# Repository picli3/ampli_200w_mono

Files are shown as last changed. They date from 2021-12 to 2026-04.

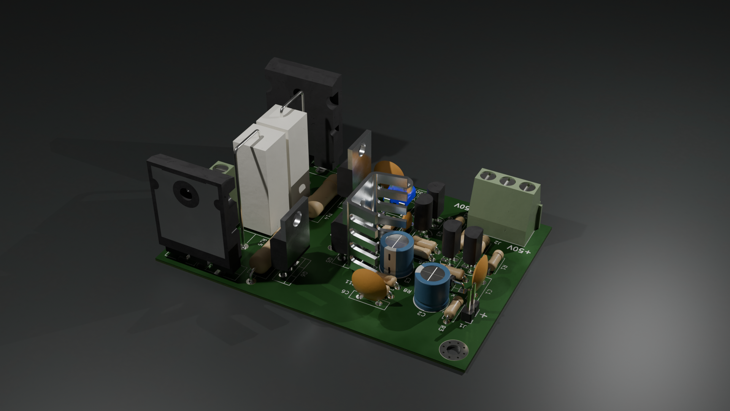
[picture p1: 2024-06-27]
untitled.png

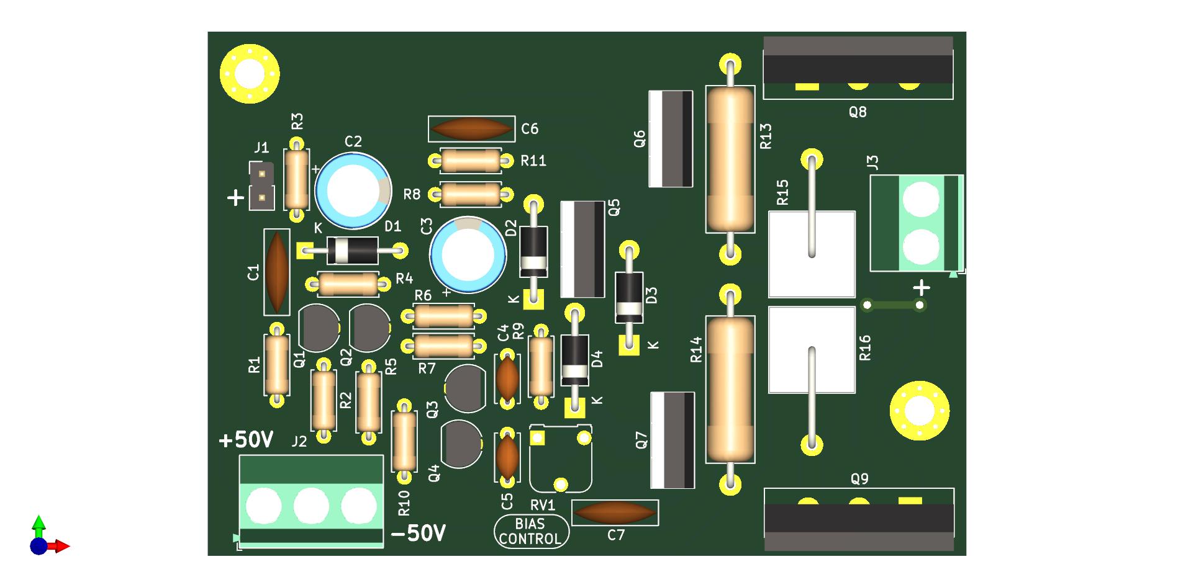
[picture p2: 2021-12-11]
pdf/amplificador_200w.jpg

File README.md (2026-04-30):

# ampli_200w_mono

Amplificador mono de alta potencia, orientado a aplicaciones de audio DIY donde se requiere una sola vía robusta de salida.

## Qué incluye
- esquemáticos o archivos de diseño en KiCad
- PCB o documentación asociada
- base reutilizable para análisis, fabricación o mejora del proyecto

## Propósito general
Este repositorio busca concentrar el diseño de hardware del proyecto en un formato editable y reutilizable, facilitando pruebas, documentación y futuras iteraciones del circuito.

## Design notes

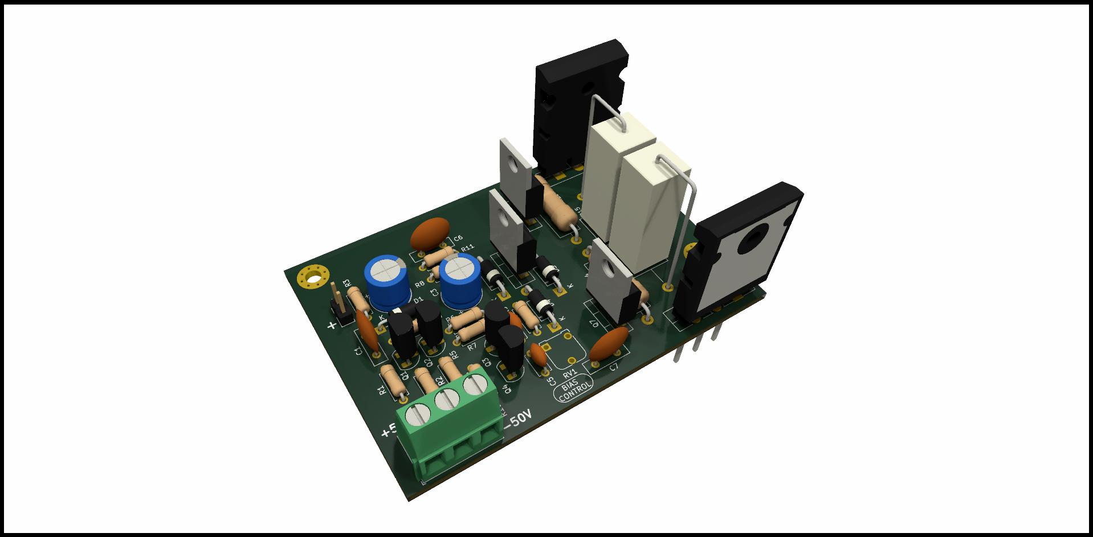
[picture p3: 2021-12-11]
pdf/amplificador_200w_ISO.jpg

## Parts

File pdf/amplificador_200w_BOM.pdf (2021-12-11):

amplificador_200w

Página 1

## AMPLIFICADOR 100W

Qty | Reference(s) | Value | Footprint | V | W
1 C1 | | 0.47uF | Capacitor_THT:C_Disc_D9.0mm_W2.5mm_P5.00mm
2 C2, C3 | | 100uF | Capacitor_THT:CP_Radial_D8.0mm_P3.50mm | 50V
2 C4, C5 | | 10pF | Capacitor_THT:C_Disc_D5.0mm_W2.5mm_P5.00mm
2 C6, C7 | | 10nF | Capacitor_THT:C_Disc_D9.0mm_W2.5mm_P5.00mm
1 D1 | | 24V | Diode_THT:D_A-405_P10.16mm_Horizontal
3 D2, D3, D4 | | 1N4007 | Diode_THT:D_DO-41_SOD81_P10.16mm_Horizontal
1 J1 | | Conn_01x03 | Connector_PinHeader_2.54mm:PinHeader_1x02_P2.54mm_Vertical
1 J2 | | Conn_01x03 | TerminalBlock_Phoenix:TerminalBlock_Phoenix_MKDS-1,5-3-5.08_1x03_P5.08mm_Horizontal
1 J3 | | Conn_01x02 | TerminalBlock_Phoenix:TerminalBlock_Phoenix_MKDS-1,5-2-5.08_1x02_P5.08mm_Horizontal
2 Q1, Q2 | | A733 | Package_TO_SOT_THT:TO-92L_HandSolder
2 Q3, Q4 | | 2SC2229 | Package_TO_SOT_THT:TO-92L_HandSolder
2 Q5, Q7 | | TIP42 | Package_TO_SOT_THT:TO-220-3_Vertical
1 Q6 | | TIP41 | Package_TO_SOT_THT:TO-220-3_Vertical
2 Q8, Q9 | | 2SC5200 | Package_TO_SOT_THT:TO-264-3_Vertical
2 R1, R7 | | 68K | Resistor_THT:R_Axial_DIN0207_L6.3mm_D2.5mm_P7.62mm_Horizontal | | 1/4W
2 R2, R5 | | 3.3K | Resistor_THT:R_Axial_DIN0207_L6.3mm_D2.5mm_P7.62mm_Horizontal | | 1/4W
1 R3 | | 4.7K | Resistor_THT:R_Axial_DIN0207_L6.3mm_D2.5mm_P7.62mm_Horizontal | | 1/4W
1 R4 | | 33K | Resistor_THT:R_Axial_DIN0207_L6.3mm_D2.5mm_P7.62mm_Horizontal | | 1/4W
1 R6 | | 1K | Resistor_THT:R_Axial_DIN0207_L6.3mm_D2.5mm_P7.62mm_Horizontal | | 1/4W
3 R8, R10, R11 | | 150 | Resistor_THT:R_Axial_DIN0207_L6.3mm_D2.5mm_P7.62mm_Horizontal | | 1/4W
1 R9 | | 10K | Resistor_THT:R_Axial_DIN0207_L6.3mm_D2.5mm_P7.62mm_Horizontal | | 1/4W
2 R13, R14 | | 100 | Resistor_THT:R_Axial_DIN0516_L15.5mm_D5.0mm_P20.32mm_Horizontal | | 2W
2 R15, R16 | | 0.33 | Resistor_THT:R_Axial_Power_L25.0mm_W9.0mm_P10.16mm_Vertical | | 5W
1 RV1 | | 200 | Potentiometer_THT:Potentiometer_Runtron_RM-065_Vertical

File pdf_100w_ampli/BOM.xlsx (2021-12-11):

Item | Qty | Reference(s) | Value | LibPart | Footprint | Datasheet | V
1 | 1 | C1 | 0.47uF | Device:C | Capacitor_THT:C_Disc_D9.0mm_W2.5mm_P5.00mm | ~
2 | 2 | C2, C3 | 100uF | Device:CP1 | Capacitor_THT:CP_Radial_D8.0mm_P3.50mm | ~ | 50V
3 | 2 | C4, C5 | 10pF | Device:C | Capacitor_THT:C_Disc_D5.0mm_W2.5mm_P5.00mm | ~
4 | 2 | C6, C7 | 10nF | Device:C | Capacitor_THT:C_Disc_D9.0mm_W2.5mm_P5.00mm | ~
5 | 1 | D1 | 24V | Device:D_Zener_ALT | Diode_THT:D_A-405_P10.16mm_Horizontal | ~
6 | 3 | D2, D3, D4 | 1N4007 | Device:D_ALT | Diode_THT:D_DO-41_SOD81_P10.16mm_Horizontal | ~
7 | 2 | H1, H2 | MountingHole | Mechanical:MountingHole | MountingHole:MountingHole_3.2mm_M3_Pad_Via | ~
8 | 1 | J1 | Conn_01x03 | Connector_Generic:Conn_01x02 | Connector_PinHeader_2.54mm:PinHeader_1x02_P2.54mm_Vertical | ~
9 | 1 | J2 | Conn_01x03 | Connector_Generic:Conn_01x03 | TerminalBlock_Phoenix:TerminalBlock_Phoenix_MKDS-1,5-3-5.08_1x03_P5.08mm_Horizontal | ~
10 | 1 | J3 | Conn_01x02 | Connector_Generic:Conn_01x02 | TerminalBlock_Phoenix:TerminalBlock_Phoenix_MKDS-1,5-2-5.08_1x02_P5.08mm_Horizontal | ~
11 | 2 | Q1, Q2 | A733 | Device:Q_PNP_EBC | Package_TO_SOT_THT:TO-92L_HandSolder | https://www.voti.nl/docs/A733.pdf
12 | 2 | Q3, Q4 | 2SC2229 | Device:Q_NPN_ECB | Package_TO_SOT_THT:TO-92L_HandSolder | ~
13 | 2 | Q5, Q7 | TIP42 | Device:Q_PNP_BCE | Package_TO_SOT_THT:TO-220-3_Vertical | ~
14 | 1 | Q6 | TIP41 | Device:Q_NPN_BCE | Package_TO_SOT_THT:TO-220-3_Vertical | ~
15 | 2 | Q8, Q9 | 2SC5200 | Device:Q_NPN_BCE | Package_TO_SOT_THT:TO-264-3_Vertical | ~
16 | 2 | R1, R7 | 68K | Device:R | Resistor_THT:R_Axial_DIN0207_L6.3mm_D2.5mm_P7.62mm_Horizontal | ~
17 | 2 | R2, R5 | 3.3K | Device:R | Resistor_THT:R_Axial_DIN0207_L6.3mm_D2.5mm_P7.62mm_Horizontal | ~
18 | 1 | R3 | 4.7K | Device:R | Resistor_THT:R_Axial_DIN0207_L6.3mm_D2.5mm_P7.62mm_Horizontal | ~
19 | 1 | R4 | 33K | Device:R | Resistor_THT:R_Axial_DIN0207_L6.3mm_D2.5mm_P7.62mm_Horizontal | ~
20 | 1 | R6 | 1K | Device:R | Resistor_THT:R_Axial_DIN0207_L6.3mm_D2.5mm_P7.62mm_Horizontal | ~
21 | 3 | R8, R10, R11 | 150 | Device:R | Resistor_THT:R_Axial_DIN0207_L6.3mm_D2.5mm_P7.62mm_Horizontal | ~
22 | 1 | R9 | 10K | Device:R | Resistor_THT:R_Axial_DIN0207_L6.3mm_D2.5mm_P7.62mm_Horizontal | ~
23 | 2 | R13, R14 | 100 | Device:R | Resistor_THT:R_Axial_DIN0516_L15.5mm_D5.0mm_P20.32mm_Horizontal | ~
24 | 2 | R15, R16 | 0.33 | Device:R | Resistor_THT:R_Axial_Power_L25.0mm_W9.0mm_P10.16mm_Vertical | ~
25 | 1 | RV1 | 1K | Device:R_POT | Potentiometer_THT:Potentiometer_Runtron_RM-065_Vertical | ~

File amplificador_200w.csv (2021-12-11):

Source: | C:\Users\eho28\repos\amplificador_200w\amplificador_200w.kicad_sch
Date: | 28/10/21 09:14:34
Tool: | Eeschema (5.99.0-12960-gccd3a1e6a9)
Generator: | C:\Program Files\KiCad\5.99\bin\scripting\plugins/bom_csv_grouped_by_value_with_fp.py
Component Count: | 41
Ref | Qnty | Value | Cmp name | Footprint | Description | Vendor
C1, | 1 | 0.47uF | C | Capacitor_THT:C_Disc_D9.0mm_W2.5mm_P5.00mm | Unpolarized capacitor
C2, C3, | 2 | 100uF | CP1-Device | Capacitor_THT:CP_Radial_D8.0mm_P3.50mm
C4, C5, | 2 | 10pF | C | Capacitor_THT:C_Disc_D5.0mm_W2.5mm_P5.00mm | Unpolarized capacitor
C6, C7, | 2 | 10nF | C | Capacitor_THT:C_Disc_D9.0mm_W2.5mm_P5.00mm | Unpolarized capacitor
D1, | 1 | 24V | D_Zener_ALT-Device | Diode_THT:D_A-405_P10.16mm_Horizontal
D2, D3, D4, | 3 | 1N4007 | D_ALT-Device | Diode_THT:D_DO-41_SOD81_P10.16mm_Horizontal
H1, H2, | 2 | MountingHole | MountingHole | MountingHole:MountingHole_3.2mm_M3_Pad_Via | Mounting Hole without connection
J1, | 1 | Conn_01x03 | Conn_01x02 | Connector_PinHeader_2.54mm:PinHeader_1x02_P2.54mm_Vertical | Generic connector, single row, 01x02, script generated (kicad-library-utils/schlib/autogen/connector/)
J2, | 1 | Conn_01x03 | Conn_01x03 | TerminalBlock_Phoenix:TerminalBlock_Phoenix_MKDS-1,5-3-5.08_1x03_P5.08mm_Horizontal | Generic connector, single row, 01x03, script generated (kicad-library-utils/schlib/autogen/connector/)
J3, | 1 | Conn_01x02 | Conn_01x02 | TerminalBlock_Phoenix:TerminalBlock_Phoenix_MKDS-1,5-2-5.08_1x02_P5.08mm_Horizontal | Generic connector, single row, 01x02, script generated (kicad-library-utils/schlib/autogen/connector/)
Q1, Q2, | 2 | A733 | Q_PNP_ECB | Package_TO_SOT_THT:TO-92L_HandSolder | PNP transistor, emitter/collector/base
Q3, Q4, | 2 | 2SC2229 | Q_NPN_ECB | Package_TO_SOT_THT:TO-92L_HandSolder | NPN transistor, emitter/collector/base
Q5, Q7, | 2 | TIP42 | Q_PNP_BCE | Package_TO_SOT_THT:TO-220-3_Vertical | PNP transistor, base/collector/emitter
Q6, | 1 | TIP41 | Q_NPN_BCE | Package_TO_SOT_THT:TO-220-3_Vertical | NPN transistor, base/collector/emitter
Q8, Q9, | 2 | 2SC5200 | Q_NPN_BCE | Package_TO_SOT_THT:TO-264-3_Vertical | NPN transistor, base/collector/emitter
R1, R7, | 2 | 68K | R | Resistor_THT:R_Axial_DIN0207_L6.3mm_D2.5mm_P7.62mm_Horizontal | Resistor
R2, R5, | 2 | 3.3K | R | Resistor_THT:R_Axial_DIN0207_L6.3mm_D2.5mm_P7.62mm_Horizontal | Resistor
R3, | 1 | 4.7K | R | Resistor_THT:R_Axial_DIN0207_L6.3mm_D2.5mm_P7.62mm_Horizontal | Resistor
R4, | 1 | 33K | R | Resistor_THT:R_Axial_DIN0207_L6.3mm_D2.5mm_P7.62mm_Horizontal | Resistor
R6, | 1 | 1K | R | Resistor_THT:R_Axial_DIN0207_L6.3mm_D2.5mm_P7.62mm_Horizontal | Resistor
R8, R10, R11, | 3 | 150 | R | Resistor_THT:R_Axial_DIN0207_L6.3mm_D2.5mm_P7.62mm_Horizontal | Resistor
R9, | 1 | 10K | R | Resistor_THT:R_Axial_DIN0207_L6.3mm_D2.5mm_P7.62mm_Horizontal | Resistor
R13, R14, | 2 | 100 | R | Resistor_THT:R_Axial_DIN0516_L15.5mm_D5.0mm_P20.32mm_Horizontal | Resistor
R15, R16, | 2 | 0.33 | R | Resistor_THT:R_Axial_Power_L25.0mm_W9.0mm_P10.16mm_Vertical | Resistor
RV1, | 1 | 200 | R_Potentiometer | Potentiometer_THT:Potentiometer_Runtron_RM-065_Vertical | Potentiometer

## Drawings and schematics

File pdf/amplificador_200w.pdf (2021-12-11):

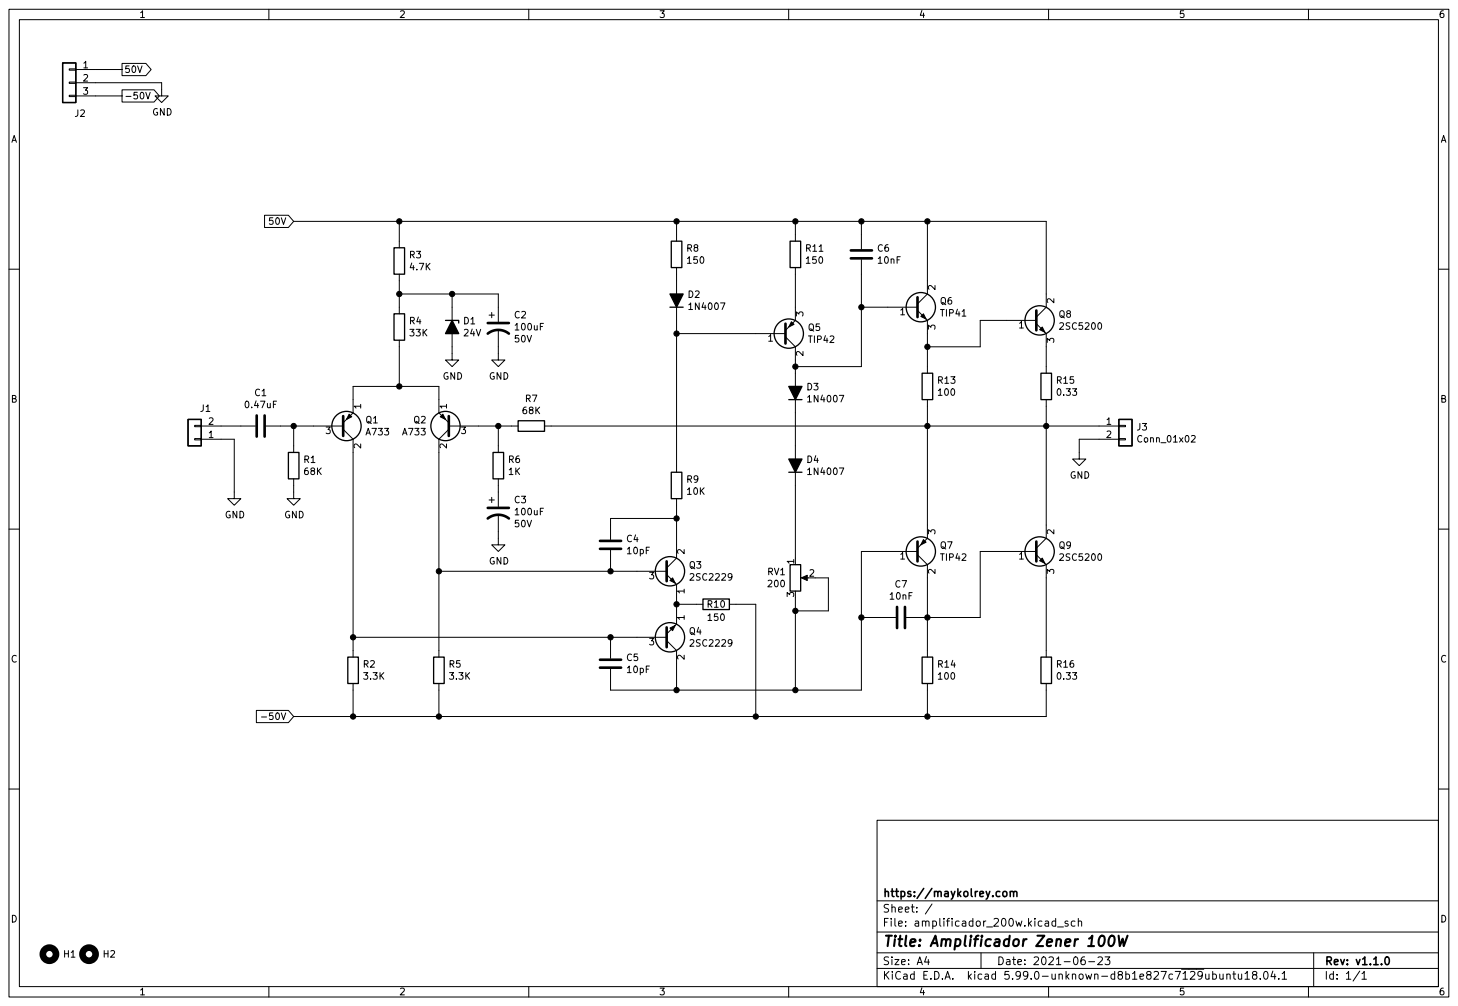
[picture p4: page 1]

File: amplificador_200w.kicad_sch Sheet: / https://maykolrey.com

Id: 1/1 Title: Amplificador Zener 100W

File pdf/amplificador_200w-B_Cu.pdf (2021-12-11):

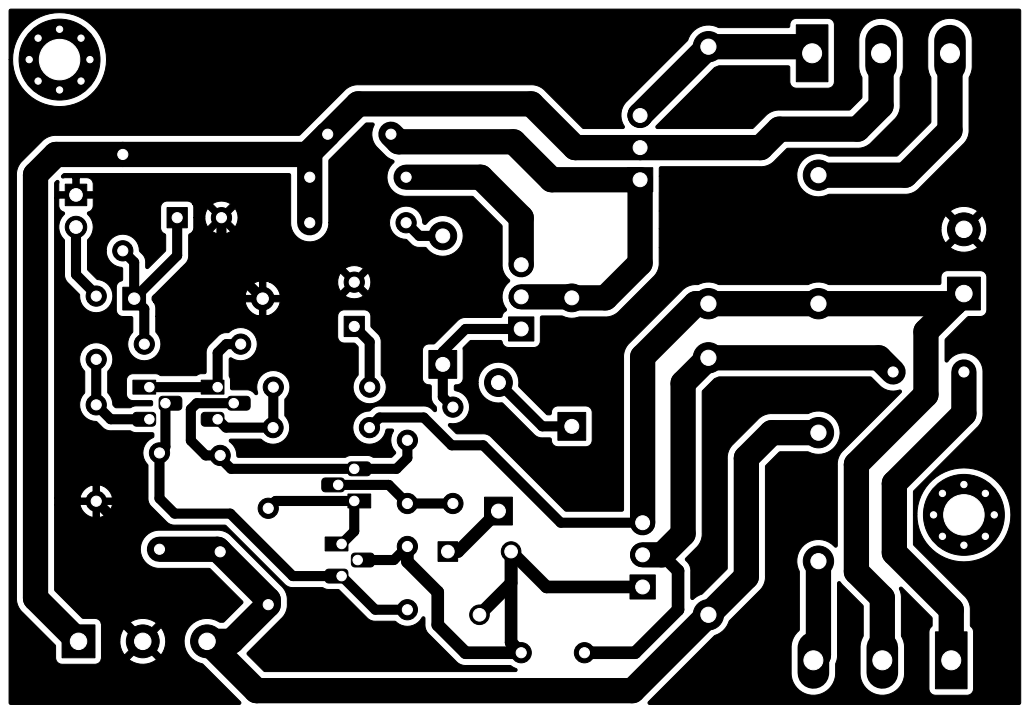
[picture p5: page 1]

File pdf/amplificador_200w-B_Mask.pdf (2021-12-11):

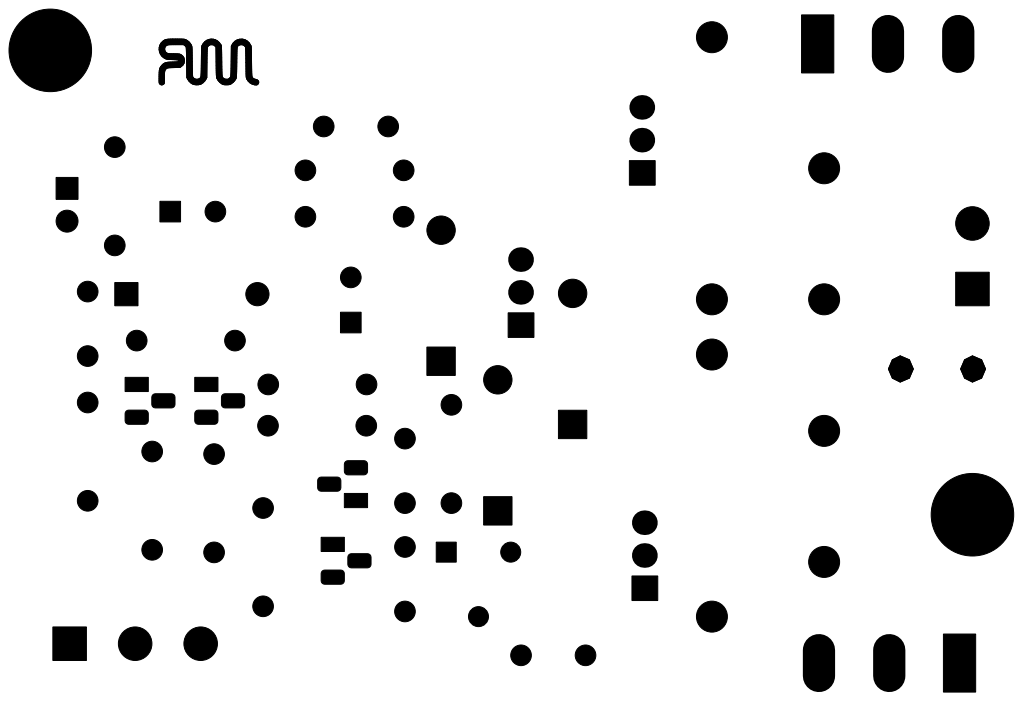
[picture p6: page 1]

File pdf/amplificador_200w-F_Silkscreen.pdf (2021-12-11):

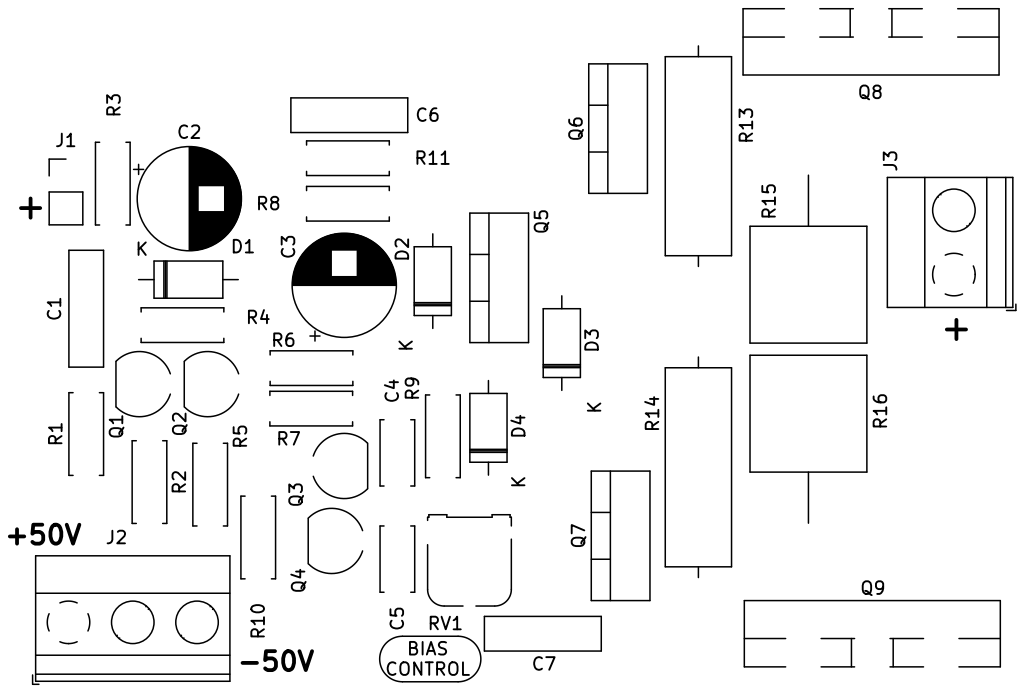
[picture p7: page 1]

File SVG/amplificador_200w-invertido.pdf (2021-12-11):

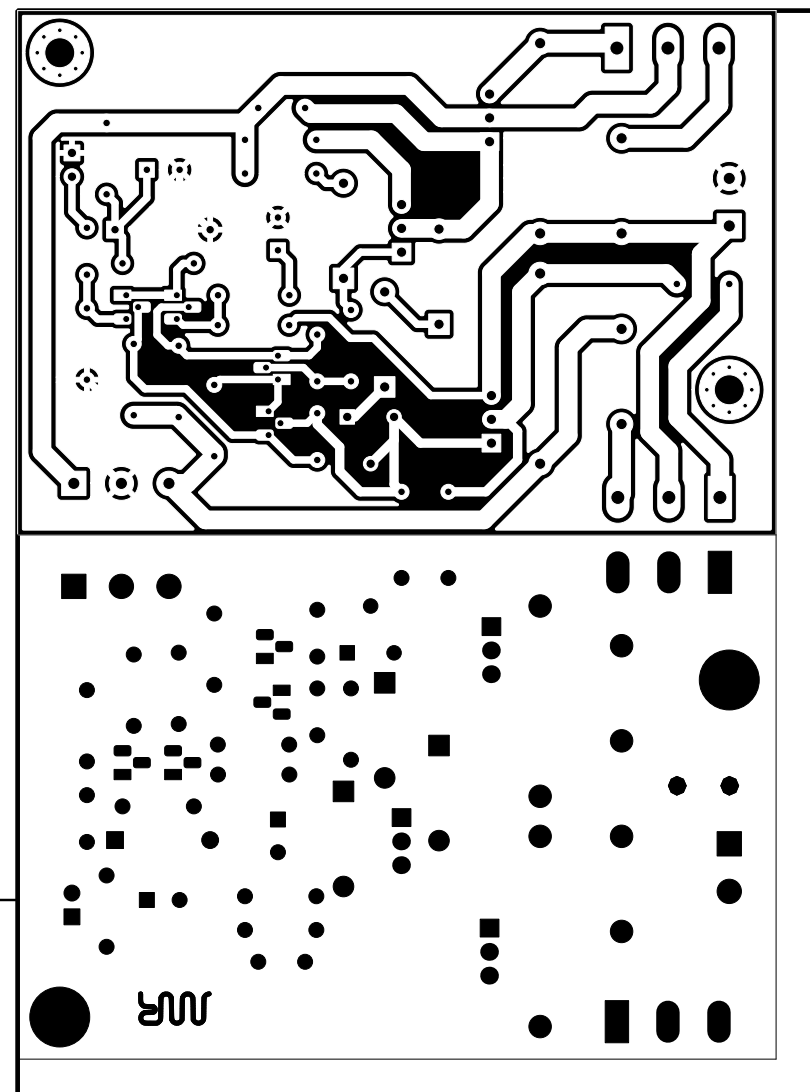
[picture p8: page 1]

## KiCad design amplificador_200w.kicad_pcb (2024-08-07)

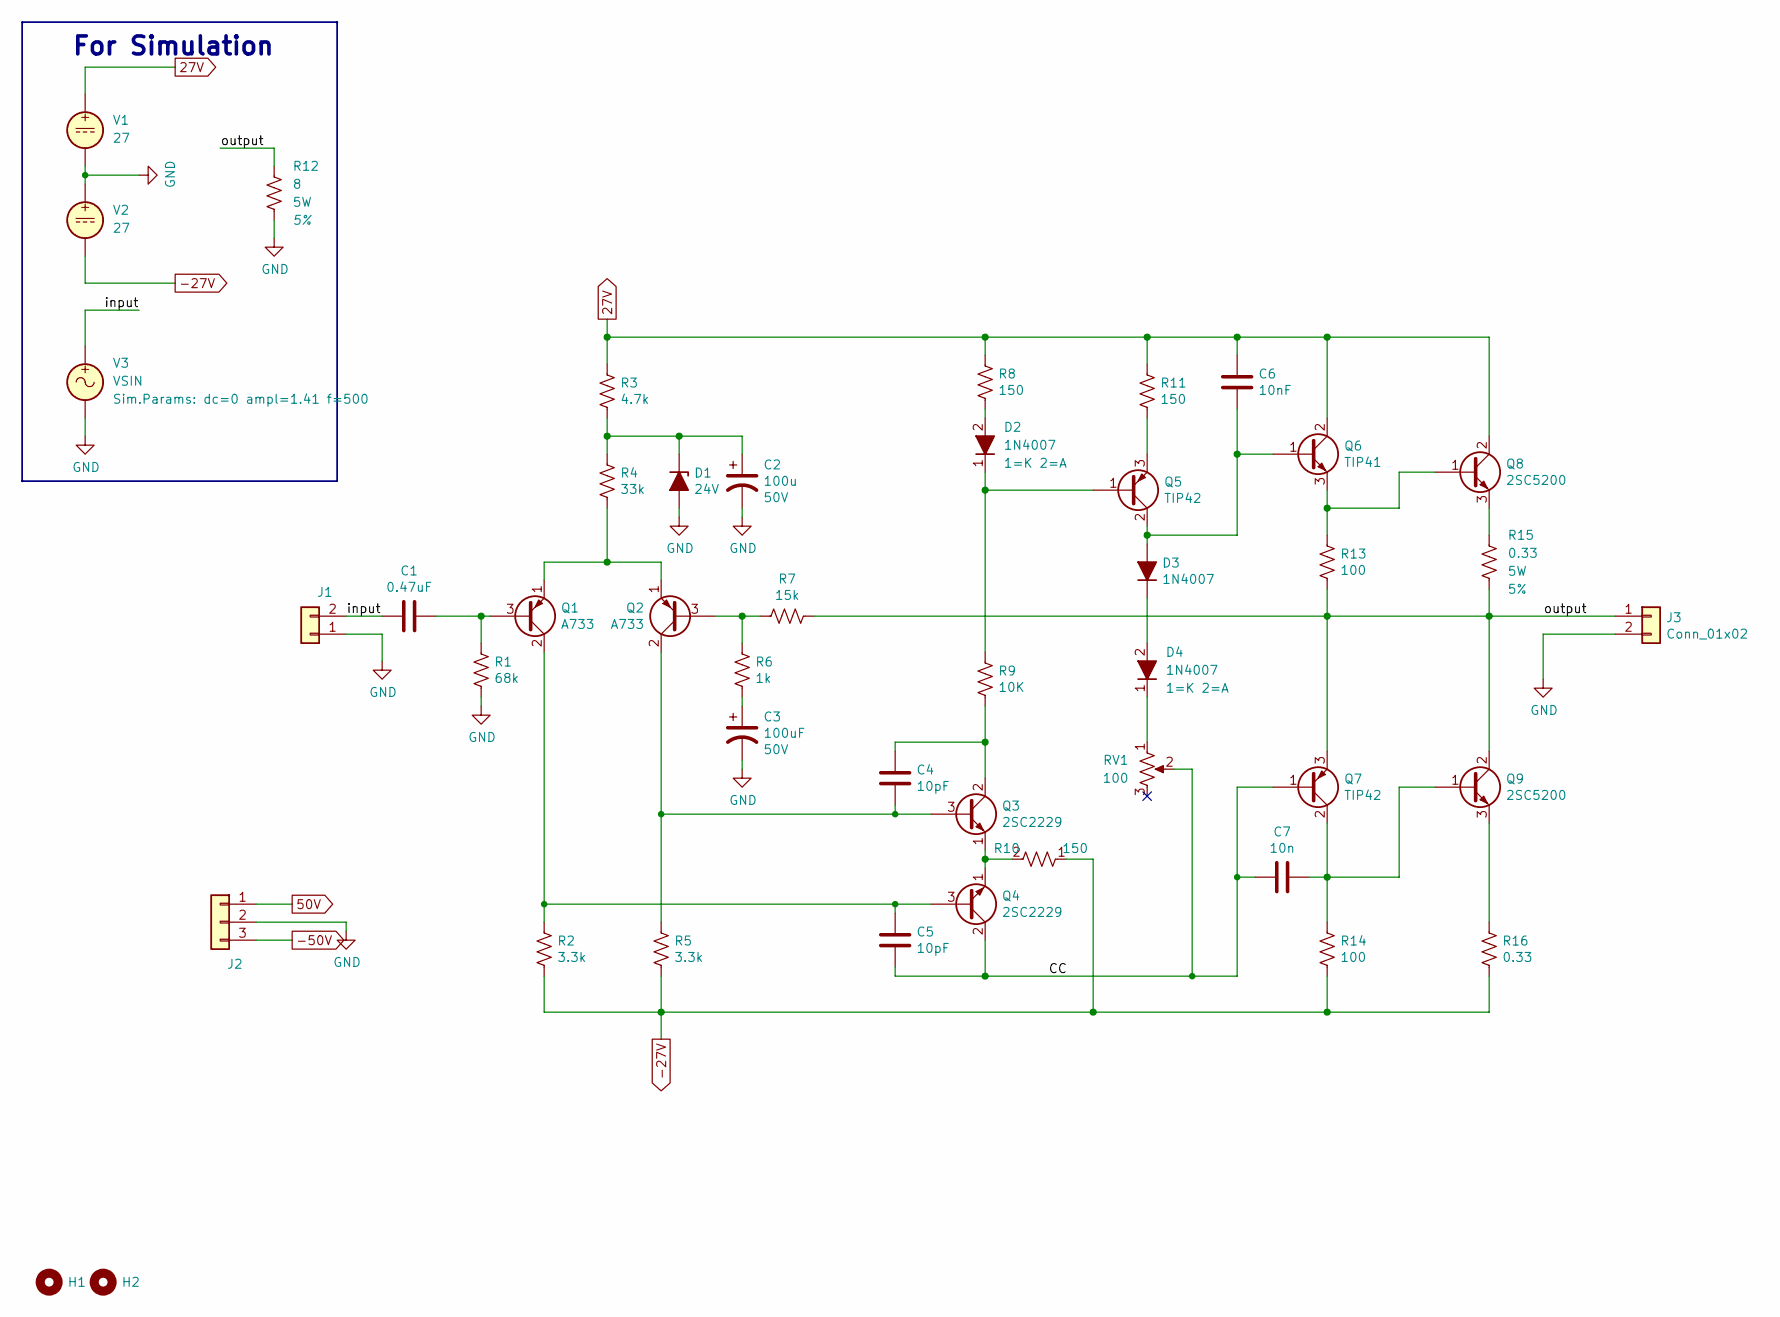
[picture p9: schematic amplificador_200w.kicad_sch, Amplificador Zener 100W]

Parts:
C1: 0.47uF; C_Disc_D9.0mm_W2.5mm_P5.00mm
C2: 100u; CP_Radial_D8.0mm_P3.50mm
C3: 100uF; CP_Radial_D8.0mm_P3.50mm
C4, C5: 10pF; C_Disc_D5.0mm_W2.5mm_P5.00mm
C6: 10nF; C_Disc_D9.0mm_W2.5mm_P5.00mm
C7: 10n; C_Disc_D9.0mm_W2.5mm_P5.00mm
D1: 24V; D_A-405_P10.16mm_Horizontal
D2, D3, D4: 1N4007; D_DO-41_SOD81_P10.16mm_Horizontal
H1, H2: MountingHole; MountingHole_3.2mm_M3_Pad_Via
J1: Conn_01x03; PinHeader_1x02_P2.54mm_Vertical
J2: Conn_01x03; TerminalBlock_Phoenix_MKDS-1,5-3-5.08_1x03_P5.08mm_Horizont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
J3: Conn_01x02; TerminalBlock_Phoenix_MKDS-1,5-2-5.08_1x02_P5.08mm_Horizont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
Q1, Q2: A733; TO-92L_HandSolder; Mfg Part # KSA733CGBU
Q3, Q4: 2SC2229; TO-92L_HandSolder
Q5, Q7: TIP42; TO-220-3_Vertical
Q6: TIP41; TO-220-3_Vertical
Q8, Q9: 2SC5200; TO-264-3_Vertical
R1: 68k; R_Axial_DIN0207_L6.3mm_D2.5mm_P7.62mm_Horizontal
R2, R5: 3.3k; R_Axial_DIN0207_L6.3mm_D2.5mm_P7.62mm_Horizontal
R3: 4.7k; R_Axial_DIN0207_L6.3mm_D2.5mm_P7.62mm_Horizontal
R4: 33k; R_Axial_DIN0207_L6.3mm_D2.5mm_P7.62mm_Horizontal
R6: 1k; R_Axial_DIN0207_L6.3mm_D2.5mm_P7.62mm_Horizontal
R7: 15k; R_Axial_DIN0207_L6.3mm_D2.5mm_P7.62mm_Horizontal
R8, R10, R11: 150; R_Axial_DIN0207_L6.3mm_D2.5mm_P7.62mm_Horizontal
R9: 10K; R_Axial_DIN0207_L6.3mm_D2.5mm_P7.62mm_Horizontal
R12: 8; R_Axial_Power_L25.0mm_W9.0mm_P10.16mm_Vertical
R13, R14: 100; R_Axial_DIN0516_L15.5mm_D5.0mm_P20.32mm_Horizontal
R15, R16: 0.33; R_Axial_Power_L25.0mm_W9.0mm_P10.16mm_Vertical
RV1: 100
V1, V2: 27
V3: VSIN

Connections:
-27V: R2.2, R5.2, R10.1, R14.1, R16.1, V2.2
-50V: J2.3
/CC: C5.1, C7.1, Q4.2 (C), Q7.1 (B), RV1.2, RV1.3
/input: C1.2, J1.2, V3.1
/output: J3.1, Q7.3 (E), Q9.2 (C), R7.1, R12.2, R13.1, R15.1
GND: C2.2, C3.2, D1.2 (A), J1.1, J2.2, J3.2, R1.2, R12.1, V1.2, V2.1, V3.2
unnamed: C3.1, R6.2
unnamed: C2.1, D1.1 (K), R3.2, R4.1
unnamed: D2.2 (A), R8.1
unnamed: D2.1 (K), Q5.1 (B), R9.2
unnamed: C6.1, D3.2 (A), Q5.2 (C), Q6.1 (B)
unnamed: D3.1 (K), D4.2 (A)
unnamed: D4.1 (K), RV1.1
unnamed: C1.1, Q1.3 (B), R1.1
unnamed: C5.2, Q1.2 (C), Q4.3 (B), R2.1
unnamed: Q1.1 (E), Q2.1 (E), R4.2
unnamed: Q2.3 (B), R6.1, R7.2
unnamed: C4.1, Q2.2 (C), Q3.3 (B), R5.1
unnamed: C4.2, Q3.2 (C), R9.1
unnamed: Q3.1 (E), Q4.1 (E), R10.2
unnamed: Q5.3 (E), R11.1
unnamed: Q6.3 (E), Q8.1 (B), R13.2
unnamed: C7.2, Q7.2 (C), Q9.1 (B), R14.2
unnamed: Q8.3 (E), R15.2
unnamed: Q9.3 (E), R16.2

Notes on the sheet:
For Simulation

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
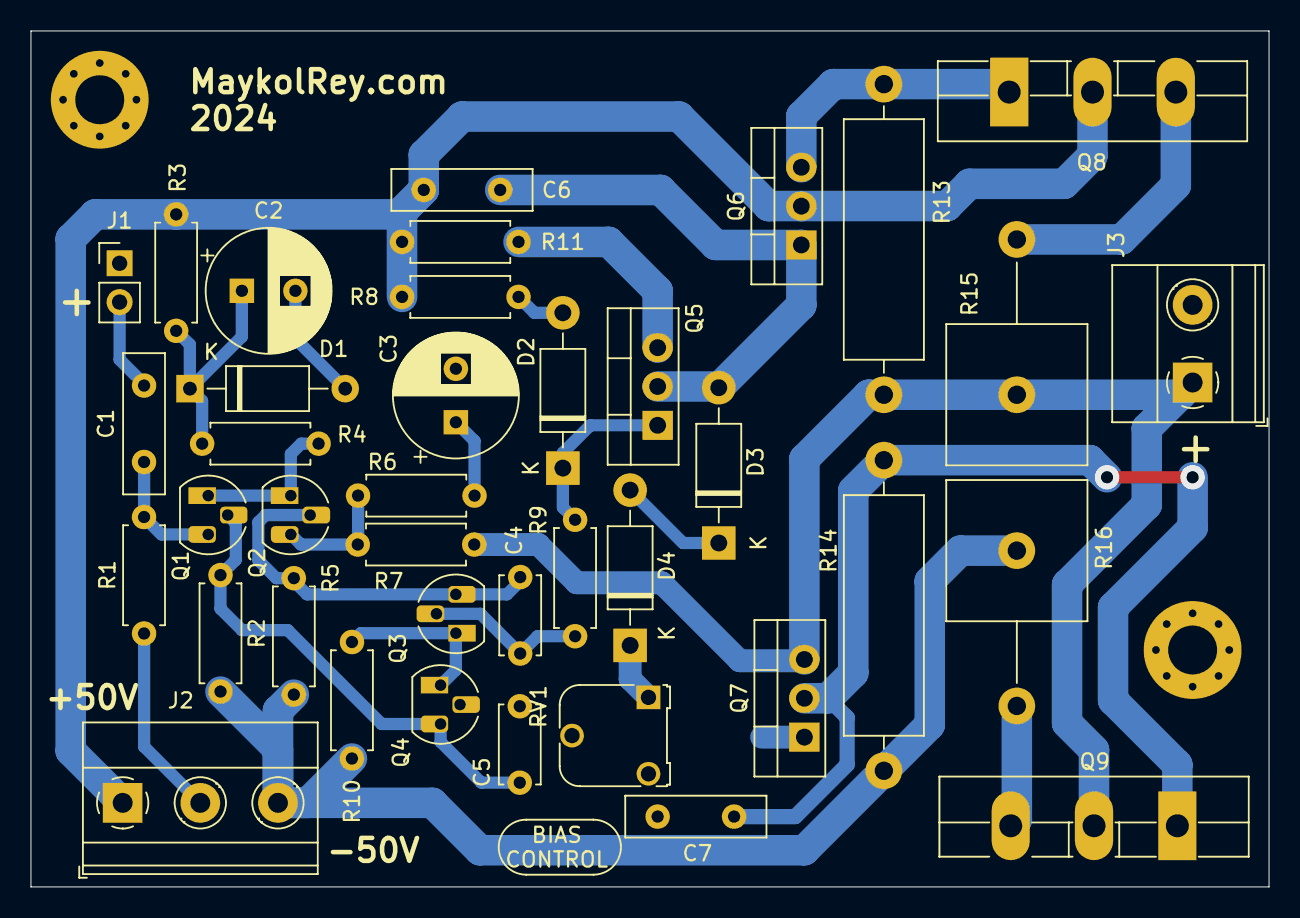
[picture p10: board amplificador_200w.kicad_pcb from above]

Board: 2 copper layers, 81.0 x 56.0 mm, 41 parts (0 on the bottom side), 25 nets.

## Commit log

2021-12-11 version provada
    [BOM.xlsx, amplificador_200w.csv, amplificador_200w.kicad_pcb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]
2024-06-27 enviando a fabricar a jlcpcb
    [amplificador_200w-B_Cu.gbr, amplificador_200w-B_Fab.gbr, amplificador_200w-B_Mask.gbr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]
2024-08-07 version simulada y probada en la realidad
    [amplificador_200w.kicad_pcb, amplificador_200w.kicad_sch]
